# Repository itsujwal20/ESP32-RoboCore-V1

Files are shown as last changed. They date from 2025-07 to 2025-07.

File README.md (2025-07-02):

# ESP32-RoboCore V1

A custom-designed 4-layer development board based on the **ESP32-WROOM-32** SoC, tailored for robotics applications and modular sensor interfacing. This board includes onboard voltage regulation, USB-UART communication, and multiple headers for I²C, PWM, and more.

---

## 🧩 Features

- **Microcontroller:** ESP32-WROOM-32
- **Power Supply:**
  - 12V Barrel Jack input
  - LM2596S-5 (5V regulator)
  - AMS1117-3.3 (3.3V LDO regulator)
- **USB-UART:** CH340C IC with USB-C support
- **Modular Headers:**
  - I²C Header
  - PWM Header
  - MPU6050 IMU Header
  - OLED Display Header
- **Push Buttons:** 2 x Tactile switches
- **3.3V & 5V Rails**
- **PCB Type:** 4-layer custom PCB
- **Keep-Out Zone:** Defined for onboard ESP32 antenna

---

## 🖼️ Images

| PCB Preview | Circuit Diagram |
|---|---|
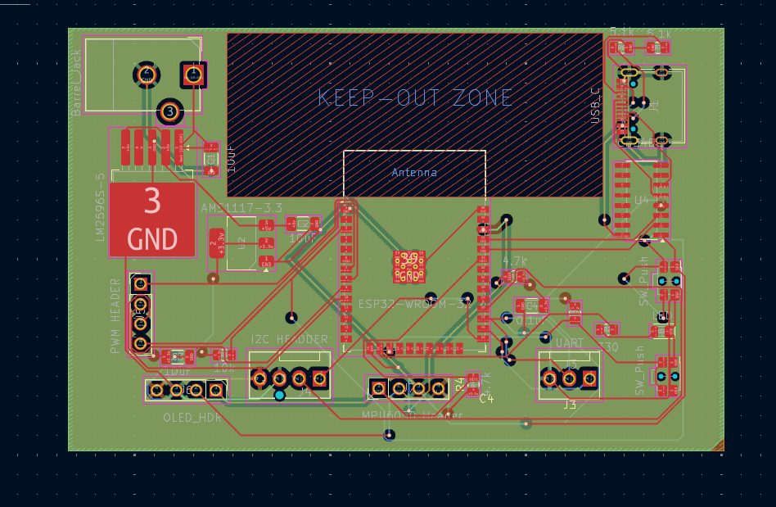
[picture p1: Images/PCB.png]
PCB
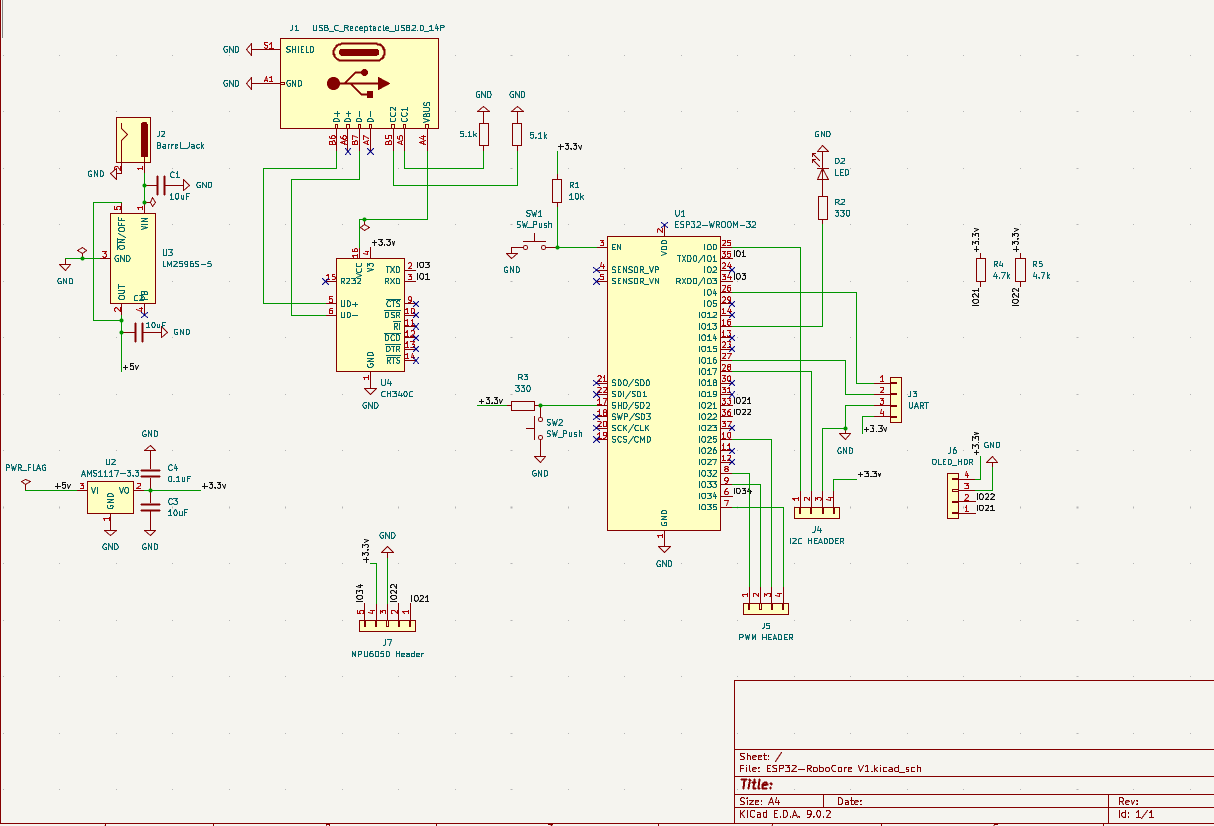
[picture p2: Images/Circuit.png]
Circuit
|  |  |

| 3D Front View | 3D Back View |
|---|---|
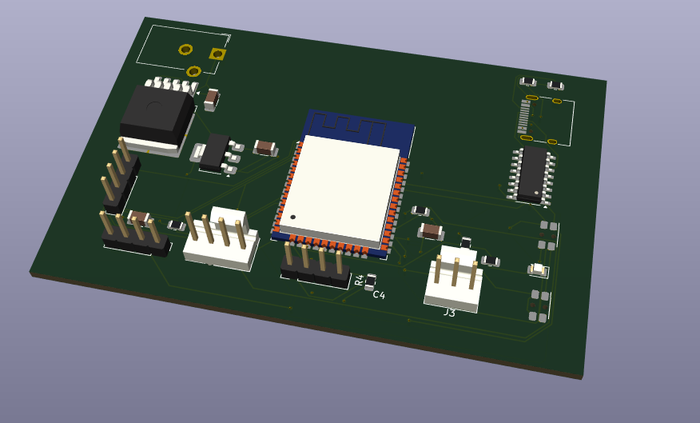
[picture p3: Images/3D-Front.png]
3D Front
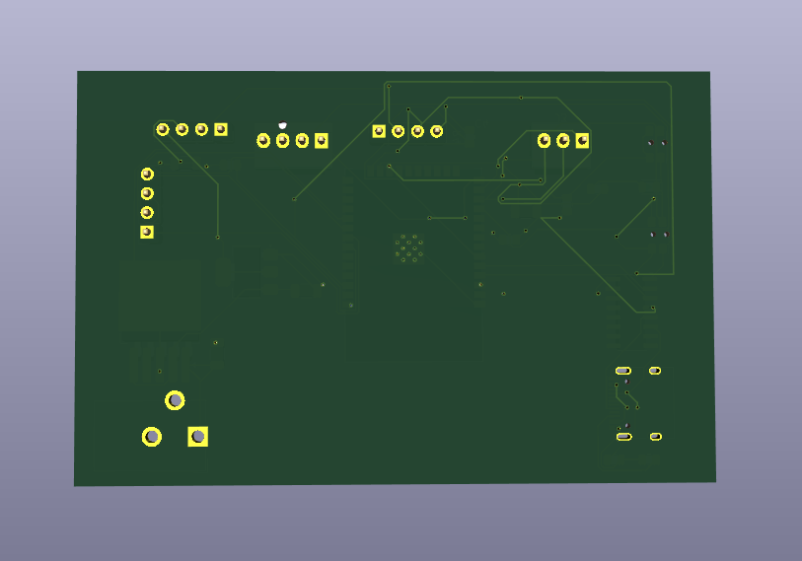
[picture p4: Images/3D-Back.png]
3D Back
|  |  |

---

## 📁 Project Structure
```
ESP32-RoboCore-V1/
├── ESP32-RoboCore V1.kicad_pcb # PCB layout
├── ESP32-RoboCore V1.kicad_sch # Schematic
├── ESP32-RoboCore V1.kicad_pro # KiCad project file
├── Gerber Files/ # Gerber files for fabrication
├── Images/ # Preview images
│ ├── 3D-Back.png
│ ├── 3D-Front.png
│ ├── Circuit.png
│ └── PCB.png
└── README.md
```

---

## 📦 Gerber Files

The production-ready Gerber files are available in the `Gerber Files/` directory. These files were generated using **KiCad** and are ready to be uploaded to any PCB fabrication service (e.g., JLCPCB, PCBWay, etc.).

---

## 📚 Tools Used

- **Schematic & PCB Design:** KiCad
- **3D Model Rendering:** KiCad 3D Viewer
- **Microcontroller:** ESP32-WROOM-32

---

## 👨‍💻 Author

**Ujwal Kumar S**  
Electronics and Electrical Engineering  
[GitHub Profile](https://github.com/itsujwal20)

---

## ⚙️ License

This project is open-source under the [MIT License](LICENSE).

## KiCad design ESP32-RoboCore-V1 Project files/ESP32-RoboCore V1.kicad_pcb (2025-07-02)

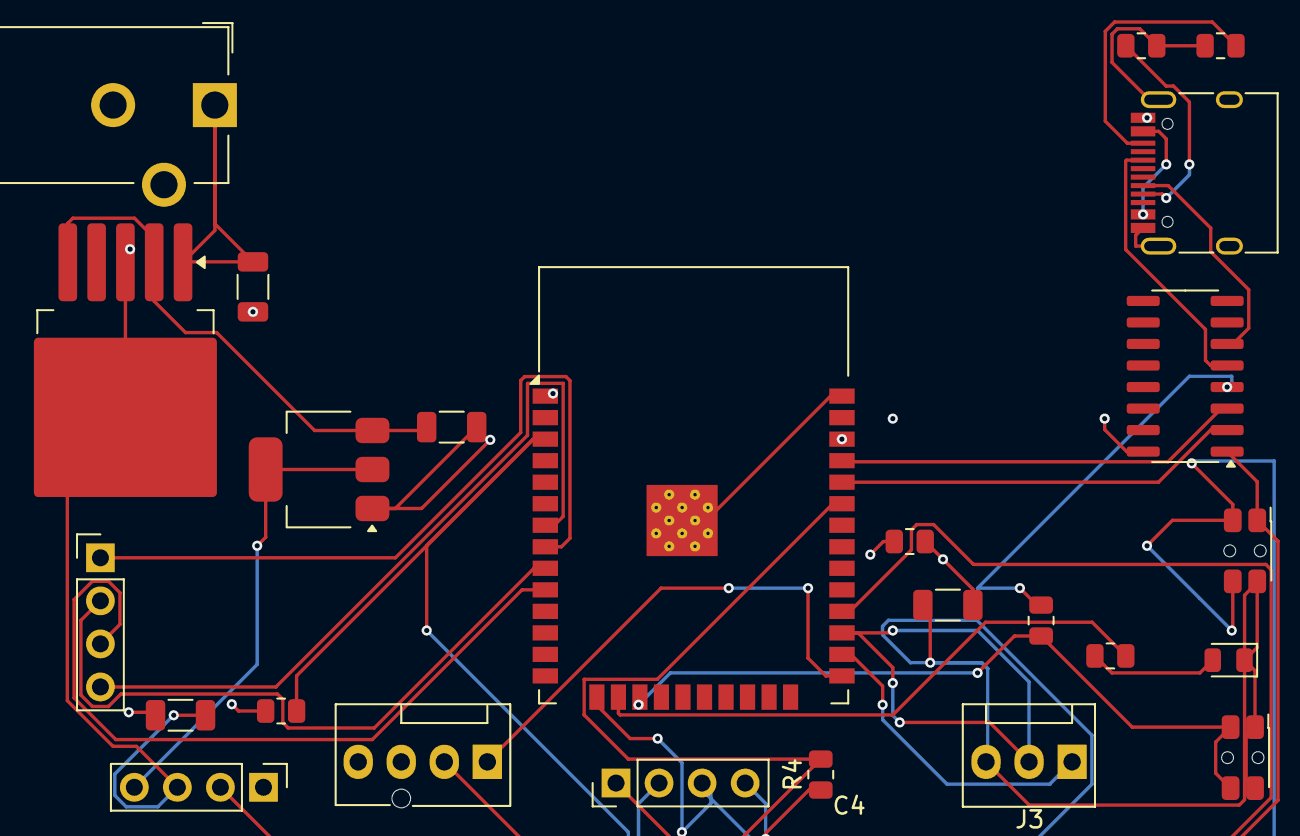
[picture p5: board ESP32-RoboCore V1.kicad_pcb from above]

Board: 4 copper layers, 25 parts (0 on the bottom side), 25 nets.

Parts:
C1, C2, C3: 10uF; C_1206_3216Metric
C4: 0.1uF; C_1206_3216Metric
D2: LED; LED_0805_2012Metric
J1: USB_C; USB_C_Receptacle_HRO_TYPE-C-31-M-12
J2: Barrel_Jack; BarrelJack_CUI_PJ-102AH_Horizontal
J3: UART; FanPinHeader_1x03_P2.54mm_Vertical
J4: I2C HEADDER; FanPinHeader_1x04_P2.54mm_Vertical
J5: PWM HEADER; PinHeader_1x04_P2.54mm_Vertical
J6: OLED_HDR; PinHeader_1x04_P2.54mm_Vertical
J7: MPU6050 Header; PinHeader_1x04_P2.54mm_Vertical
R1: 10k; R_0805_2012Metric
R2, R3: 330; R_0805_2012Metric
R4, R5: 4.7k; R_0805_2012Metric
R6, R7: 5.1k; R_0805_2012Metric
SW1, SW2: SW_Push; SW_SPST_EVQP7C
U1: ESP32-WROOM-32
U2: AMS1117-3.3; SOT-223-3_TabPin2
U3: LM2596S-5; TO-263-5_TabPin3
U4: CH340C; SOIC-16_3.9x9.9mm_P1.27mm

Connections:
/+3.3v: C3.1, C4.2, J4.4, J6.4, J7.4, R1.1, R3.1, R4.1, R5.1, U2.2 (VO), U4.4 (V3)
/+5v: C2.1, U2.3 (VI), U3.2 (OUT), U3.5 (~ON/OFF)
/IO1: U1.35 (TXD0/IO1), U4.3 (RXD)
/IO3: U1.34 (RXD0/IO3), U4.2 (TXD)
/IO21: J6.1, J7.1, R4.2, U1.33 (IO21)
/IO22: J6.2, J7.2, R5.2, U1.36 (IO22)
GND: C1.2, C2.2, C3.2, C4.1, D2.1 (K), J1.A1 (GND), J1.A12 (GND), J1.B1 (GND), J1.B12 (GND), J1.S1 (SHIELD), J2.2, J3.3, J4.3, J6.3, J7.3, R6.1, R7.1, SW1.1, SW2.1, U1.1 (GND), U1.15 (GND), U1.38 (GND), U1.39 (GND), U2.1 (GND), U3.3 (GND), U4.1 (GND)
unnamed: D2.2 (A), R2.1
unnamed: J1.A5 (CC1), R6.2
unnamed: J1.B5 (CC2), R7.2
unnamed: J3.1, U1.26 (IO4)
unnamed: J3.2, U1.27 (IO16)
unnamed: J4.1, U1.25 (IO0)
unnamed: J4.2, U1.28 (IO17)
unnamed: J5.1, U1.8 (IO32)
unnamed: J5.2, U1.9 (IO33)
unnamed: J5.3, U1.10 (IO25)
unnamed: J5.4, U1.7 (IO35)
unnamed: R1.2, SW1.2, U1.3 (EN)
unnamed: R2.2, U1.16 (IO13)
unnamed: R3.2, SW2.2, U1.17 (SHD/SD2)
unnamed: C1.1, J2.1, U3.1 (VIN)
unnamed: J1.B6 (D+), U4.5 (UD+)
unnamed: J1.B7 (D-), U4.6 (UD-)
unnamed: J1.A4 (VBUS), J1.A9 (VBUS), J1.B4 (VBUS), J1.B9 (VBUS), U4.16 (VCC)
